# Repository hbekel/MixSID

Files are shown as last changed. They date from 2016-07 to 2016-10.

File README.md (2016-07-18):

# MixSID
*flexible Stereo-SID-board with integrated channel mixer*

The MixSID is a stereo SID board for the C64 that can be used with any combination 
of SID models on a wide range of C64 mainboards.

Features include an integrated stereo channel mixer, 
pragmatic stereo addressing scheme, flexible handling of io areas,
onboard audio input, output and digiboost circuits, 
dedicated stereo output, full paddle compatibility and versatile digital control.

For more information, please see the project page, available in both 
[english](http://www.henning-bekel.de/mixsid) and [german](http://www.henning-bekel.de/mixsid/de).

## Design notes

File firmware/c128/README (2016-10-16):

!! NOTE: THIS IS NOT THE FIRMWARE FOR THE GAL ON THE MIXSID ITSELF !!

Regardless of which machine the MixSID is installed to, its own GAL
chip uses the same logic (firmware/mixsid.gal).

The GAL logic in this directory (firmware/c128/u3.gal) is intended to
replace the 74LS138 multiplexer at U3 in a C128 flat case or C128D
plastic case mainboard (Assy. 310378) in order to make the secondary
SID appear at $d500 in stereo addressing mode while in C64 mode.

In more general terms, this modification extends the SID CS signal
created by U3 to additionally cover $D500-$D5FF in C64 mode.

On a plain C64, the SID occupies a large address range from $D400 to
$D7FF. The SID appears mirrored every 32 bytes in this area. This
allows stereo sid boards to simply decode the address for the second
SID based on the mainboards SID CS signal and just two additional
address lines (most likely A5 and A8) in order to further divide this
IO area and to place the second SID at either $D420 or $D500 (the most
common addresses used by stereo tunes).

But on a C128, the SID CS signal is only asserted in the range
$D400-$D4FF in both C128 and C64 mode. This was done because in C128
mode, the MMU appears at $D500 and the VDC appears at $D600. In C64
mode, the MMU is not visible, while the VDC is still visible at
$D600. Because the SID CS signal is never asserted for $D500-$D5FF in
either mode (even though this area is free in C64 mode), a second SID
will simply not appear at $D500 in C64 mode, rendering any common
stereo SID board useless for playing back stereo tunes at $D500 on a
C128 in C64 mode.

Although it would be possible for a stereo SID board to decode the
$d500 area on its own (without relying on the already decoded SID CS
signal), it would be much more complicated and involve additional
address lines for the user to connect.

Therefore the only practival way to get the second SID on $D500 in C64
is to extend the C128 SID CS logic to include $D500-$D5FF with this
little hack.

In order to apply this hack, the 74LS128 on U3 needs to be replaced
with a 16V8 GAL.

First remove the 74LS138 and the ceramic capatitor (C3) above.

Solder in a small 100nF capacitor on the bottom side of the PCB to
replace C3.

Then prepare a 20 pin precision socket by cutting the lower two pins
on both sides so that it can be inserted in place of the 16 pin
74LS138. Also connect Pin 8 of the socket to pin 10 in order to supply
GND to the GAL. It's ok to include pin 9 as well, since it is not
connected in this GAL setup.

Then solder in the socket and add two additional wires on the bottom
side.

Add a wire to connect pin 16 of the GAL to pin 15 of the 8721 (U11).

Add a second wire to connect pin 18 to pin 7 of the GAL. This is
required to get the IO2 signal out at the same place.

Now program and insert the GAL into the socket. If all went well, both
C128 and C64 mode should work as usual. If you have a stereo SID board
installed, configure it to place the second SID at $D500. You should
now be able to play stereo tunes using the second SID at $D500 in C64
mode.

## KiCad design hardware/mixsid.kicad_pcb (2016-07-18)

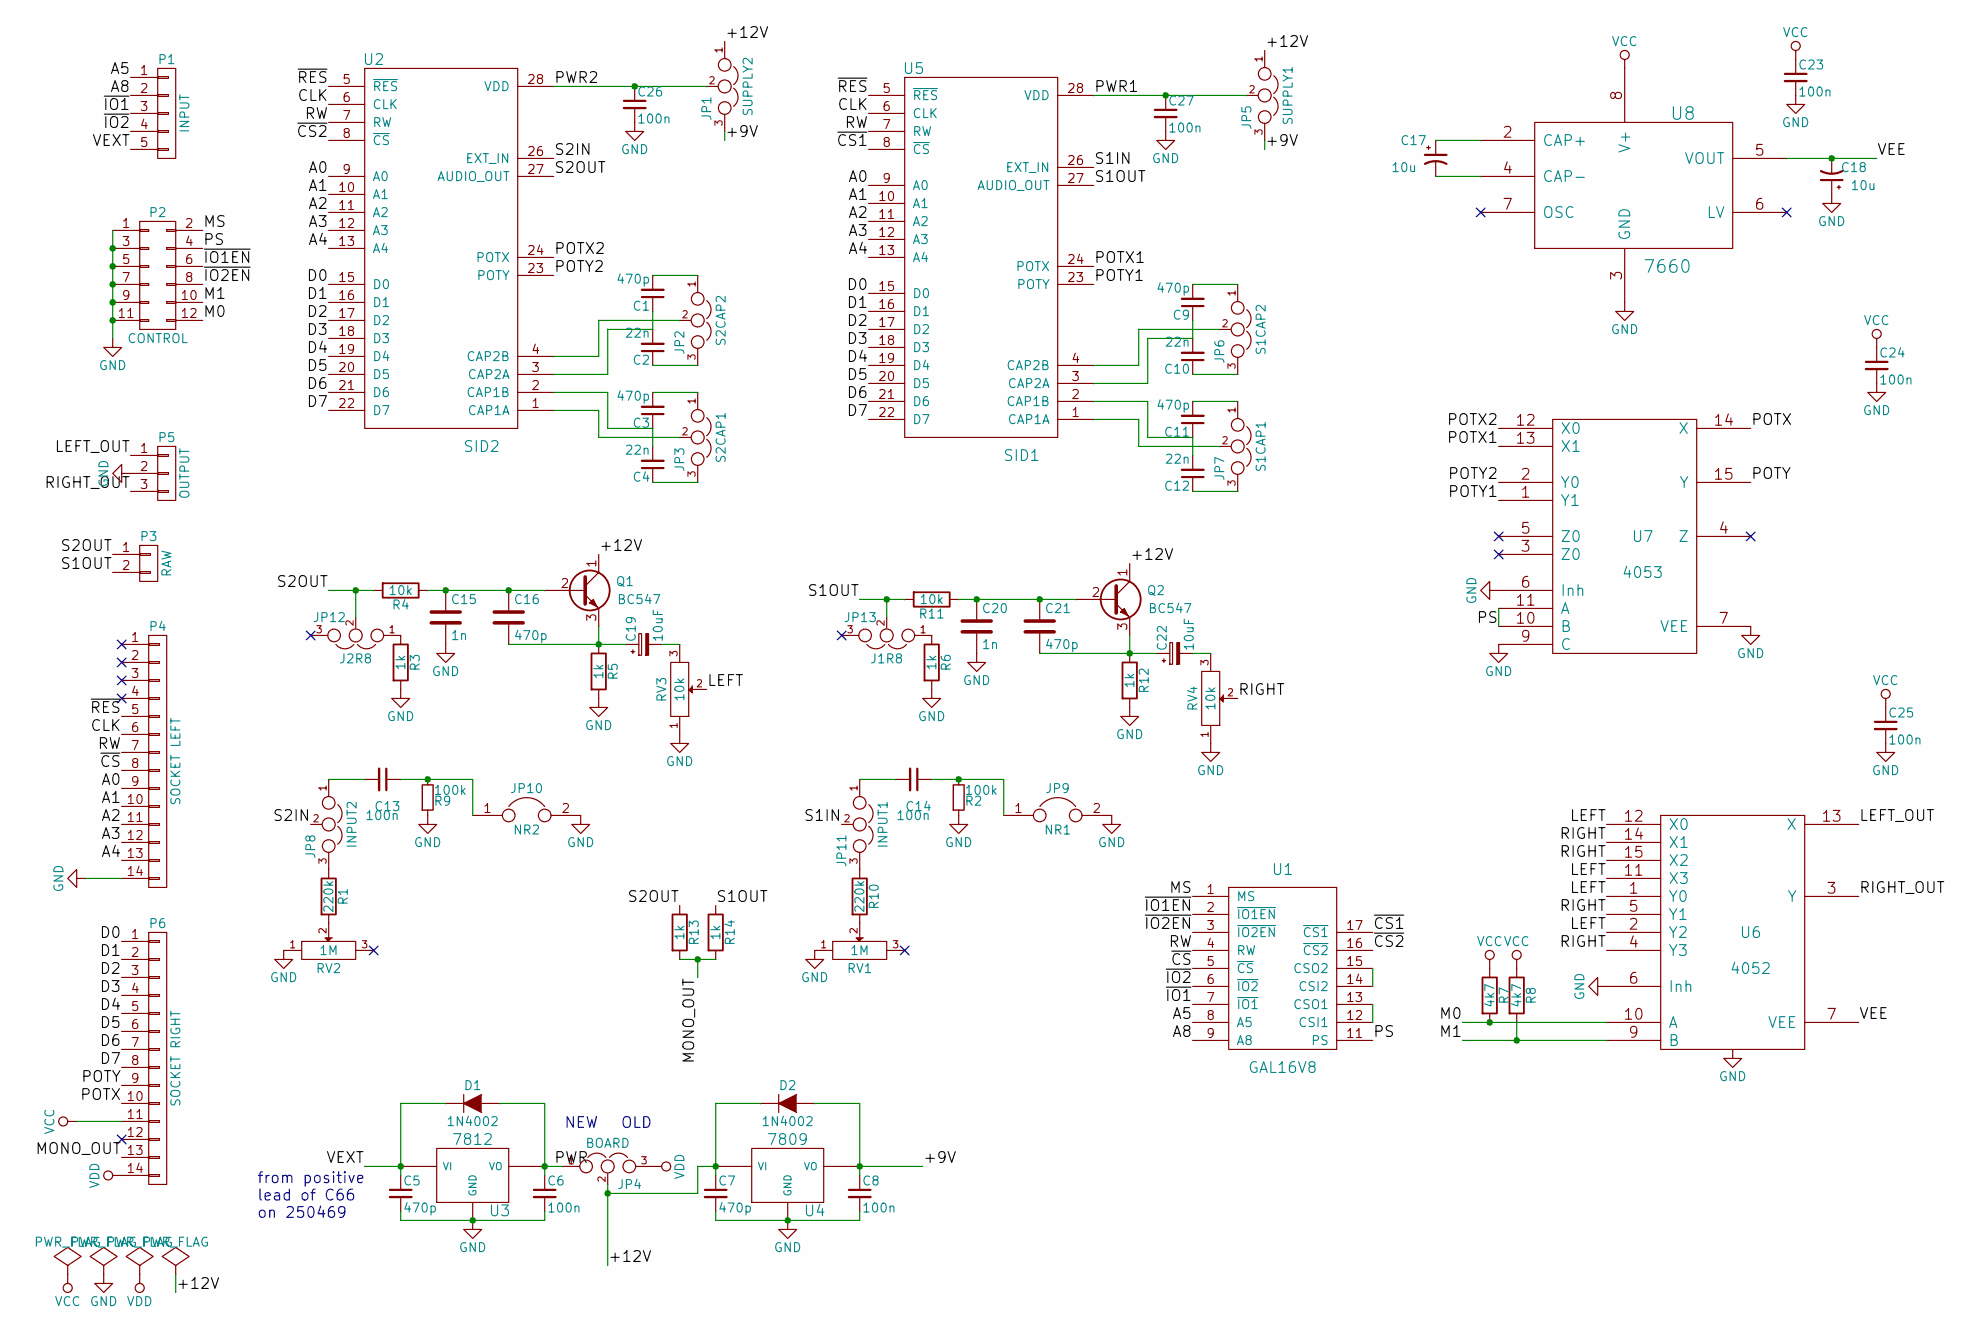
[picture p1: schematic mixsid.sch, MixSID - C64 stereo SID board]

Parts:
C1, C3, C5, C7, C9, C11, C16, C21: 470p; C_Disc_D3_P2.5
C2, C4, C10, C12: 22n; C_Disc_D3_P2.5
C6, C8, C13, C14, C23, C24, C25, C26, C27: 100n; C_Disc_D3_P2.5
C15, C20: 1n; C_Disc_D3_P2.5
C17, C18: 10u; C_Radial_D5_L6_P2.5
C19, C22: 10uF; C_Radial_D5_L6_P2.5
D1, D2: 1N4002; DO-41
JP1: SUPPLY2; Pin_Header_Straight_1x03_Pitch2.00mm
JP2: S2CAP2; Pin_Header_Straight_1x03_Pitch2.00mm
JP3: S2CAP1; Pin_Header_Straight_1x03_Pitch2.00mm
JP4: BOARD; Pin_Header_Straight_1x03
JP5: SUPPLY1; Pin_Header_Straight_1x03_Pitch2.00mm
JP6: S1CAP2; Pin_Header_Straight_1x03_Pitch2.00mm
JP7: S1CAP1; Pin_Header_Straight_1x03_Pitch2.00mm
JP8: INPUT2; Pin_Header_Straight_1x03_Pitch2.00mm
JP9: NR1; Pin_Header_Straight_1x02
JP10: NR2; Pin_Header_Straight_1x02
JP11: INPUT1; Pin_Header_Straight_1x03_Pitch2.00mm
JP12: J2R8; Pin_Header_Straight_1x03_Pitch2.00mm
JP13: J1R8; Pin_Header_Straight_1x03_Pitch2.00mm
P1: INPUT; Pin_Header_Straight_1x05
P2: CONTROL; Pin_Header_Straight_2x06
P3: RAW; Pin_Header_Straight_1x02
P4: SOCKET LEFT; Pin_Header_Straight_1x14
P5: OUTPUT; Pin_Header_Straight_1x03
P6: SOCKET RIGHT; Pin_Header_Straight_1x14
Q1, Q2: BC547; TO-92_Inline_Narrow_Oval
R1, R10: 220k; R1
R2, R9: 100k; R1
R3, R5, R6, R12, R13, R14: 1k; R1
R4, R11: 10k; R1
R7, R8: 4k7; R1
RV1, RV2: 1M; Potentiometer_Bourns_3296W_3-8Zoll_Inline_ScrewUp
RV3, RV4: 10k; Potentiometer_Bourns_3339P_Angular_ScrewUp
U1: GAL16V8; DIP-20_W7.62mm
U2: SID2; DIP-28_W15.24mm
U3: 7812; TO-220
U4: 7809; TO-220
U5: SID1; DIP-28_W15.24mm
U6: 4052; DIP-16_W7.62mm
U7: 4053; DIP-16_W7.62mm
U8: 7660; DIP-8_W7.62mm

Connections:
/+9V: C8.1, D2.2 (A), JP1.3, JP5.3, U4.3 (VO)
/+12V: C7.1, D2.1 (K), JP1.1, JP4.2, JP5.1, Q1.1 (C), Q2.1 (C), U4.1 (VI)
/A0: P4.9, U2.9 (A0), U5.9 (A0)
/A1: P4.10, U2.10 (A1), U5.10 (A1)
/A2: P4.11, U2.11 (A2), U5.11 (A2)
/A3: P4.12, U2.12 (A3), U5.12 (A3)
/A4: P4.13, U2.13 (A4), U5.13 (A4)
/A5: P1.1, U1.8 (A5)
/A8: P1.2, U1.9 (A8)
/CLK: P4.6, U2.6 (CLK), U5.6 (CLK)
/D0: P6.1, U2.15 (D0), U5.15 (D0)
/D1: P6.2, U2.16 (D1), U5.16 (D1)
/D2: P6.3, U2.17 (D2), U5.17 (D2)
/D3: P6.4, U2.18 (D3), U5.18 (D3)
/D4: P6.5, U2.19 (D4), U5.19 (D4)
/D5: P6.6, U2.20 (D5), U5.20 (D5)
/D6: P6.7, U2.21 (D6), U5.21 (D6)
/D7: P6.8, U2.22 (D7), U5.22 (D7)
/LEFT: RV3.2, U6.1 (Y0), U6.2 (Y2), U6.11 (X3), U6.12 (X0)
/LEFT_OUT: P5.1, U6.13 (X)
/M0: P2.12, R7.2, U6.10 (A)
/M1: P2.10, R8.2, U6.9 (B)
/MONO_OUT: P6.13, R13.2, R14.2
/MS: P2.2, U1.1 (MS)
/POTX: P6.10, U7.14 (X)
/POTX1: U5.24 (POTX), U7.13 (X1)
/POTX2: U2.24 (POTX), U7.12 (X0)
/POTY: P6.9, U7.15 (Y)
/POTY1: U5.23 (POTY), U7.1 (Y1)
/POTY2: U2.23 (POTY), U7.2 (Y0)
/PS: P2.4, U1.11 (PS), U7.10 (B), U7.11 (A)
/PWR: C6.1, D1.2 (A), JP4.1, U3.3 (VO)
/PWR1: C27.1, JP5.2, U5.28 (VDD)
/PWR2: C26.1, JP1.2, U2.28 (VDD)
/RIGHT: RV4.2, U6.4 (Y3), U6.5 (Y1), U6.14 (X1), U6.15 (X2)
/RIGHT_OUT: P5.3, U6.3 (Y)
/RW: P4.7, U1.4 (RW), U2.7 (RW), U5.7 (RW)
/S1IN: JP11.2, U5.26 (EXT_IN)
/S1OUT: JP13.2, P3.2, R11.2, R14.1, U5.27 (AUDIO_OUT)
/S2IN: JP8.2, U2.26 (EXT_IN)
/S2OUT: JP12.2, P3.1, R4.2, R13.1, U2.27 (AUDIO_OUT)
/VEE: C18.2, U6.7 (VEE), U8.5 (VOUT)
/VEXT: C5.1, D1.1 (K), P1.5, U3.1 (VI)
/~CS: P4.8, U1.5 (~CS)
/~CS1: U1.17 (~CS1), U5.8 (~CS)
/~CS2: U1.16 (~CS2), U2.8 (~CS)
/~IO1: P1.3, U1.7 (~IO1)
/~IO1EN: P2.6, U1.2 (~IO1EN)
/~IO2: P1.4, U1.6 (~IO2)
/~IO2EN: P2.8, U1.3 (~IO2EN)
/~RES: P4.5, U2.5 (~RES), U5.5 (~RES)
GND: C5.2, C6.2, C7.2, C8.2, C15.2, C18.1, C20.2, C23.2, C24.2, C25.2, C26.2, C27.2, JP9.2, JP10.2, P2.1, P2.3, P2.5, P2.7, P2.9, P2.11, P4.14, P5.2, R2.1, R3.2, R5.2, R6.2, R9.1, R12.2, RV1.1, RV2.1, RV3.1, RV4.1, U1.10 (GND), U2.14 (GND), U3.2 (GND), U4.2 (GND), U5.14 (GND), U6.6 (Inh), U6.8 (VSS), U7.6 (Inh), U7.7 (VEE), U7.8 (GND), U7.9 (C), U8.3 (GND)
unnamed: C1.1, C2.2, U2.3 (CAP2A)
unnamed: C1.2, JP2.1
unnamed: C2.1, JP2.3
unnamed: C3.1, C4.2, U2.2 (CAP1B)
unnamed: C3.2, JP3.1
unnamed: C4.1, JP3.3
unnamed: C9.2, JP6.1
unnamed: C10.1, JP6.3
unnamed: C9.1, C10.2, U5.3 (CAP2A)
unnamed: C11.1, C12.2, U5.2 (CAP1B)
unnamed: C11.2, JP7.1
unnamed: C12.1, JP7.3
unnamed: C13.1, JP10.1, R9.2
unnamed: C13.2, JP8.1
unnamed: C14.1, JP9.1, R2.2
unnamed: C14.2, JP11.1
unnamed: C15.1, C16.1, Q1.2 (B), R4.1
unnamed: C16.2, C19.1, Q1.3 (E), R5.1
unnamed: C17.1, U8.2 (CAP+)
unnamed: C17.2, U8.4 (CAP-)
unnamed: C19.2, RV3.3
unnamed: C20.1, C21.1, Q2.2 (B), R11.1
unnamed: C21.2, C22.1, Q2.3 (E), R12.1
unnamed: C22.2, RV4.3
unnamed: JP2.2, U2.4 (CAP2B)
unnamed: JP3.2, U2.1 (CAP1A)
unnamed: JP6.2, U5.4 (CAP2B)
unnamed: JP7.2, U5.1 (CAP1A)
unnamed: JP8.3, R1.1
unnamed: JP11.3, R10.1
unnamed: JP12.1, R3.1
unnamed: JP13.1, R6.1
unnamed: R1.2, RV2.2
unnamed: R10.2, RV1.2
unnamed: U1.12 (CSI1), U1.13 (CSO1)
unnamed: U1.14 (CSI2), U1.15 (CSO2)
VCC: C23.1, C24.1, C25.1, P6.11, R7.1, R8.1, U1.20 (VCC), U2.25 (VCC), U5.25 (VCC), U6.16 (VCC), U7.16 (VCC), U8.8 (V+)
VDD: JP4.3, P6.14

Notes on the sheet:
NEW
OLD
from positive lead of C66 on 250469

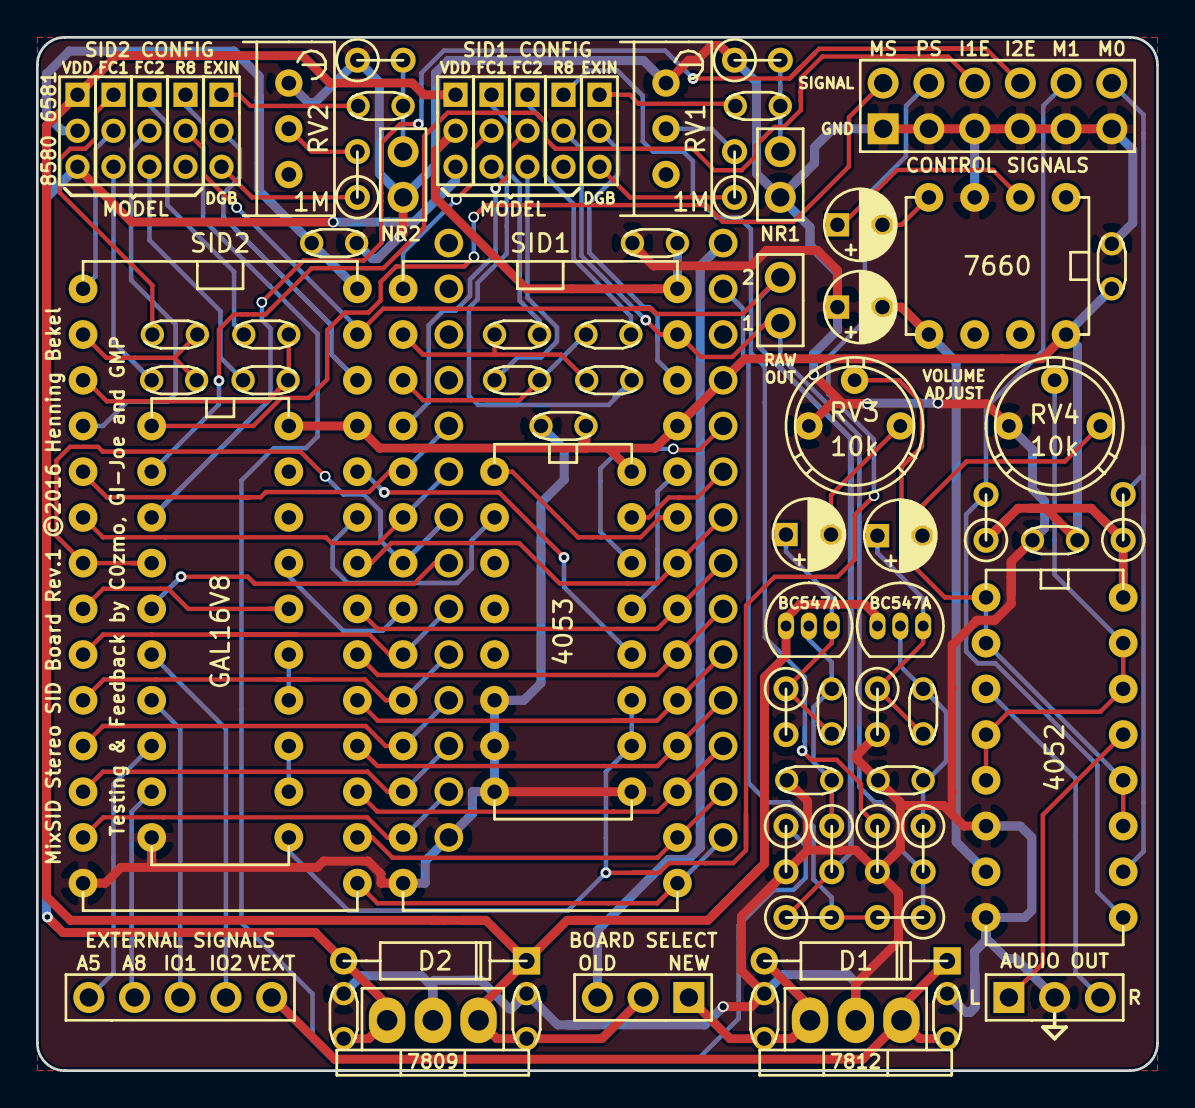
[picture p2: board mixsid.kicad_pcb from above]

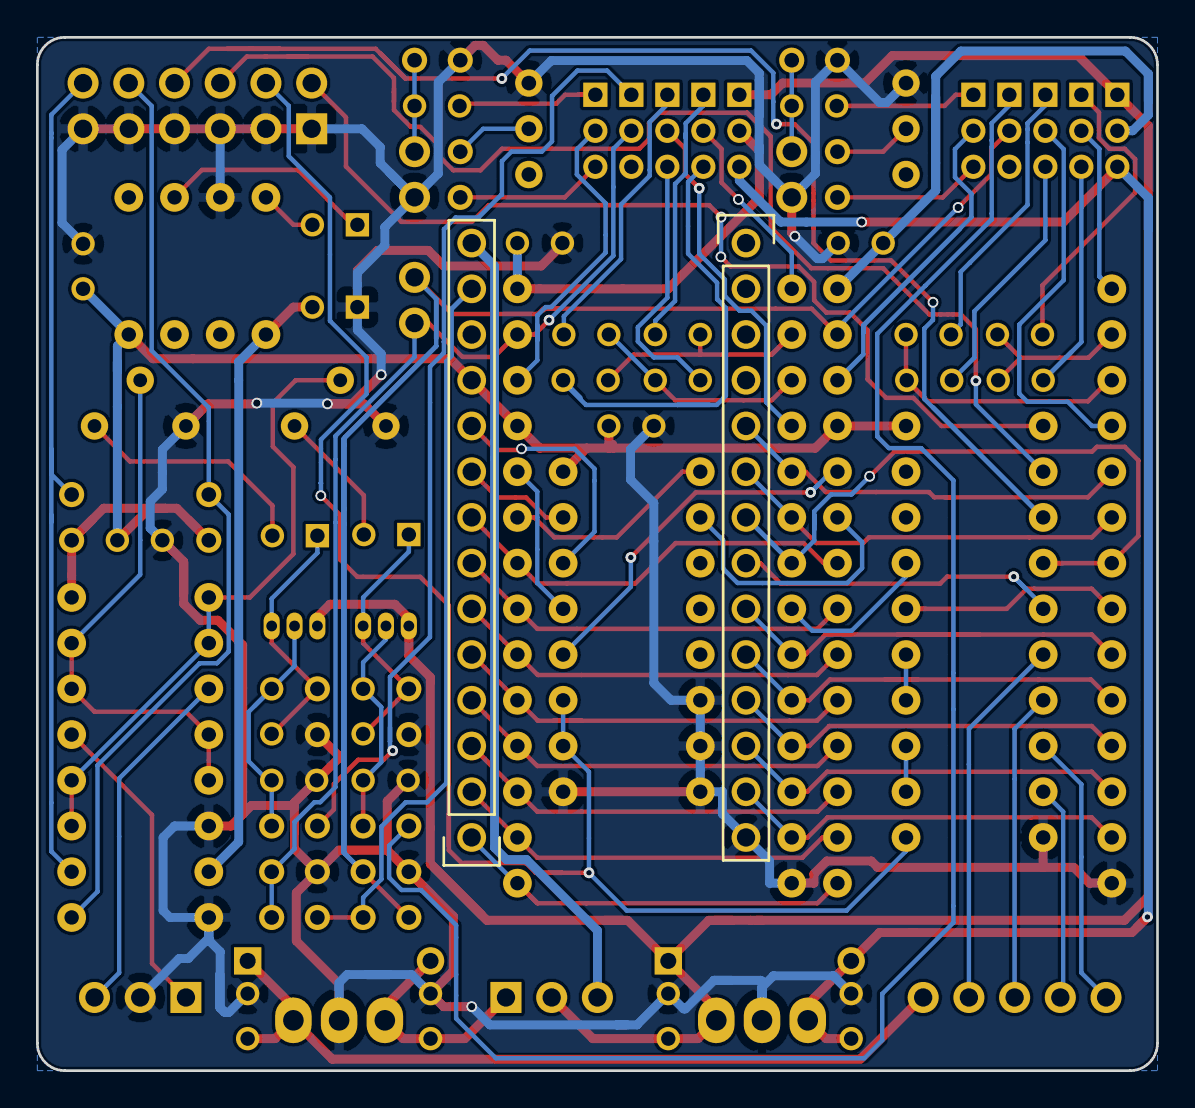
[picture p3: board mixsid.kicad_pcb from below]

Board: 2 copper layers, 62.2 x 57.4 mm, 76 parts (2 on the bottom side), 90 nets.

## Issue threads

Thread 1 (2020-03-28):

IO1EN, IO2EN, PS, MS signals do not have pull up resistors

Sgw32, 2020-03-28:
Hi,

I am working on my MixSIDs and I've found that my GALs are normally level-LOW at these pins. This causes logic of GAL to work incorrect, because it is assumed that we short these signals to GND.
So, the proposed solution is to add pull-up resistors to these lines.

Best regards,
Fedor.

hbekel, 2020-03-28:
What kind of GALs are you using? The original Lattice GAL16V8 and the currently available Atmel ATF16V8B I ship have active internal pull-ups, thus no external pull-ups were added to the board.

Sgw32, 2020-03-29:
According to the logo, they are from Lattice. Anyway they can be counterfeit since they are ordered from some Chinese supplier. Anyway, adding SMD pads for pull-ups is a good option. I can do it and add a merge request, if you want.

hbekel, 2020-04-01:
Adding SMD components is out of scope for this project. I also won't add parts to support devices not working as specified.

Closed 2020-04-01.

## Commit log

2016-03-03 Added hardware and firmware folders, added empty kicad project
    [smartsid.kicad_pcb, smartsid.sch]
2016-03-03 Hardware: First rough draft of schematics and pcb placement
    [smartsid.dsn, smartsid.kicad_pcb, smartsid.sch]
2016-03-04 Hardware: Added mixing and simple opamp output circuit
    [smartsid.dsn, smartsid.kicad_pcb, smartsid.sch]
2016-03-04 Hardware: Added notes about where to get +16v on 250469
    [smartsid.kicad_pcb, smartsid.sch]
2016-03-07 Hardware: Added optional digifix circuits for both chips
    [smartsid.dsn, smartsid.kicad_pcb, smartsid.sch]
2016-03-07 Hardware/Firmware: Supply separate IO enable lines (IO1EN, IO2EN)
    [smartsid.kicad_pcb, smartsid.sch]
2016-03-07 Hardware: Removed digifix circuits, added 7660, mix after opamps
    The 4052 can only mix signals within 2-8V and VCC must be <10V. Therefore
    the amplified output must be mixed.
    [smartsid.dsn, smartsid.kicad_pcb, smartsid.sch]
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2016-03-09 Hardware: Added some proper pinheaders, new routing, added more docs
    [smartsid.dsn, smartsid.kicad_pcb, smartsid.sch]
2016-03-09 Hardware: Added pullups for M0 and M1, rerouted
    [smartsid.dsn, smartsid.kicad_pcb, smartsid.sch]
2016-03-10 Hardware: Improved routing, changed opamp from TL072 to OPA132
    [smartsid.kicad_pcb, smartsid.sch]
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2016-03-12 Hardware: Fixed POTX/POTY connected to SID2
    [smartsid.dsn, smartsid.kicad_pcb]
2016-03-14 Hardware: Now using original output circuits instead of opamp
    [smartsid.dsn, smartsid.kicad_pcb, smartsid.sch]
2016-03-15 Hardware: Use pin headers instead of dip socket for the sid socket
    [smartsid.kicad_pcb, smartsid.sch]
2016-03-17 Hardware: Rearranged components, made control lines usable with jumpers
    [smartsid.dsn, smartsid.kicad_pcb, smartsid.sch]
2016-03-19 Hardware: Added optional mono mixing into existing output circuit
    [smartsid.dsn, smartsid.kicad_pcb, smartsid.sch]
2016-03-19 Hardware: Rearranged components below sids to fit between sockets
    [smartsid.dsn, smartsid.kicad_pcb]
2016-03-21 Hardware: Fixed transistor symbols/footprints and extin jumper positions
    [smartsid.dsn, smartsid.kicad_pcb, smartsid.sch]
2016-03-21 Hardware: Fixed wrong SID socket placement (mirrored), improved routing
    [smartsid.dsn, smartsid.kicad_pcb, smartsid.sch]
2016-03-21 Hardware: Cleaned up silkscreen, added markings, improved routing
    [smartsid.kicad_pcb]
2016-03-21 Hardware: Corrected filter capacitor values for 6581 (470p)
    [smartsid.kicad_pcb, smartsid.sch]
2016-03-22 Hardware: Improved silkscreen, corrected pot refs
    [smartsid.kicad_pcb, smartsid.sch]
2016-03-22 Hardware: Improved silkscreen, added warning labels on board jumper
    [smartsid.kicad_pcb]
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2016-04-08 Hardware: Fixed decoupling caps (now polarized), removed gerbers
    [smartsid.kicad_pcb, smartsid.sch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]
2016-04-11 Hardware: Fixed orientation of VEE decoupling caps on silkscreen
    [smartsid.kicad_pcb]
2016-04-11 Hardware: Fixed values of digifix safety resistors (220k instead of 200)
    [smartsid.kicad_pcb, smartsid.sch]
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2016-04-11 Hardware: Adjusted regulator bypass cap values to 470p
    [smartsid.kicad_pcb, smartsid.sch]
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2016-04-11 Hardware: Removed SID2 pot connector, moved board select jumper
    [smartsid.kicad_pcb, smartsid.sch]
2016-04-11 Hardware: Renamed +16V line to VEXT, improved silk screen
    [smartsid.kicad_pcb, smartsid.sch]
2016-04-11 Hardware: Corrected order of SIDs on audio channels, default mix setting
    Now the left sid appears on the left channel and the right sid on the right
    channel. Also the default mix state (without driving M0 and M1) has been
    changed to Left/Right. This should match expectations.
    [smartsid.dsn, smartsid.kicad_pcb, smartsid.sch]
2016-04-11 Hardware: Removed priority select, rearranged GAL pin layout
    Switching SID priorities does not seem very useful and will break paddles
    when priority is swapped in stereo addressing mode.
    [smartsid.dsn, smartsid.kicad_pcb, smartsid.sch]
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2016-04-12 Hardware: Flipped VEE bypass cap allowing less ambigious silkscreen
    [smartsid.kicad_pcb]
2016-04-13 Hardware: Rearranged components to increase top clearance, rerouted
    [smartsid.dsn, smartsid.kicad_pcb]
2016-04-14 Hardware: Added explicit ground path from power supply to signal ground
    [smartsid.kicad_pcb]
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2016-04-14 Hardware: Improved routing, decreased pin header pads for SID socket
    [mixsid.kicad_pcb]
2016-04-15 Hardware: Improved routing, placement of 7812 and caps, silkscreen
    [mixsid.kicad_pcb, mixsid.sch]
2016-04-15 Hardware: Improved routing of GND and VEXT around voltage regulators
    [mixsid.kicad_pcb]
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2016-04-26 Hardware: Added voltage dividers for optional volume adjustments
    [mixsid.kicad_pcb, mixsid.sch]
2016-04-26 Hardware: Changed 7660 caps to small electrolytics, improved silkscreen
    [mixsid.kicad_pcb, mixsid.sch]
2016-04-27 Hardware: Improved routing, scaled caps 3d models to size, improved 3d view
    [mixsid.kicad_pcb]
2016-04-28 Hardware: Moved bottom connectors slightly up to save some more space
    [mixsid.kicad_pcb]
2016-04-28 Hardware: Priority, paddle multiplexing, volume adjust, bigger board size
    Priority select has been reimplemented, allowing to virtually swap sids in
    terms of addressing (which SID stays at home and which one goes stereo).
    A 4053 multiplexer has been added to keep the paddles working regardless of
    priority. Paddle lines are always routed to the SID currently at $d400.
    Two pots have been added to allow volume adjustments before mixing in order
    to adjust two different models in overall volume (6581 are usually louder).
    [mixsid.dsn, mixsid.kicad_pcb, mixsid.sch]
2016-04-29 Hardware: Replaced balance pots with round types (bourns 3339), rearranged
    [mixsid.dsn, mixsid.kicad_pcb, mixsid.sch]
2016-04-29 Firmware/Hardware: RW2 signal controls SID2 RW during parallel addressing
    Depending on RW2, SID2 is write-only or read-write when addressed alongside
    SID1.
    The default setting is write-only to assure proper paddle support.
    For mono tunes that use the readable registers for special effects,
    parallel addressing would result in only one SID playing those effects
    properly, thus RW2 allows the user to make both sids read-write.
    [mixsid.dsn, mixsid.kicad_pcb, mixsid.sch]
2016-04-30 Hardware: Use round pots fot digifix as well
    [mixsid.dsn, mixsid.kicad_pcb, mixsid.sch]
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2016-05-02 Hardware: Use rect pots for digifix again, placed volume pods horizontally
    [mixsid.dsn, mixsid.kicad_pcb, mixsid.sch]
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2016-05-04 Hardware: Added raw audio out terminal, improved routing
    [mixsid.kicad_pcb, mixsid.sch]
2016-05-04 Revert "Hardware: Added raw audio out terminal, improved routing"
    This reverts commit 8f31b2ae4ef6d7f69e92e6d42a67aa70f75f1e9c.
    [mixsid.kicad_pcb, mixsid.sch]
2016-05-04 Hardware: Swapped MS/PS, improved routing, silkscreen
    [mixsid.kicad_pcb, mixsid.sch]
2016-05-04 Hardware: Prototype 3: Added gerber files for production
    [mixsid.kicad_pcb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]
2016-05-11 Hardware: Fixed connection and orientation of volume pots
    [mixsid.kicad_pcb, mixsid.sch]
2016-05-11 Hardware: Added pin header to access raw audio out as well
    [mixsid.kicad_pcb, mixsid.sch]
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2016-05-13 Hardware: Improved component placement, cap orientation for 7660
    [mixsid.kicad_pcb]
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2016-05-17 Hardware: Added R8 Jumpers, Feed SID specific VDD into output stages
    [mixsid.dsn, mixsid.kicad_pcb, mixsid.sch]
2016-05-18 Hardware: Reverted to +12V for both output stages, rerouted, refined
    [mixsid.dsn, mixsid.kicad_pcb, mixsid.sch]
2016-05-20 Hardware: Changed orientation of 7660 caps
    Provide common orientation for all polarized caps on the board.
    [mixsid.kicad_pcb]
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2016-05-23 Hardware: Added bypass caps at SID VDD supplies
    [mixsid.kicad_pcb, mixsid.sch]
2016-05-23 Hardware: Added protection diodes to regulators, board height increased
    [mixsid.dsn, mixsid.kicad_pcb, mixsid.sch]
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2016-06-01 Hardware: Improved 3d view, added short legged TO-220 model
    [mixsid.kicad_pcb]
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2016-06-10 Hardware/Firmware: Removed selective write-only logic again, not required
    The previously added logic for keeping only the POTX and POTY lines
    write-only has proven unneccessary and has thus been reverted. Now all
    readable registers are disabled for the secondary SID in parallel mode
    again. The previously introduced RW2 signal is still unneccessary. Both
    paddles and OSC3/ENV3 effects work well in parallel mode after all.
    [mixsid.kicad_pcb, mixsid.sch]
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

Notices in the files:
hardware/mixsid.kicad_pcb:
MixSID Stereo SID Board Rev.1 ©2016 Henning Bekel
